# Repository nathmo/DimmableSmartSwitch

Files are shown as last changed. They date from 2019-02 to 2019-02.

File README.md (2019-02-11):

DimmableSmartSwitch

This repo contains the schematic and the layout for an ESP32 based
dual channel smart dimmer.
The ESP32 is intended to run under ESP-easy (a firmware that with native support of MQTT and wifi).
This smart dimmer work for Inductive and Capacitive load both in AC or DC.
The circuit is triggered on crossing zero (if the Load power supply is AC)
The circuit contains a current sensing circuitery on both channel, 2 capacitive touch input and
a microphone to stream audio for voice recognition (on another device (like a raspberry pi)) and obviously the circuitery to dim the load
A PLC transcienver may be added in futur revision
(PLC transcienver : A chip that allow to transmit data over power line)

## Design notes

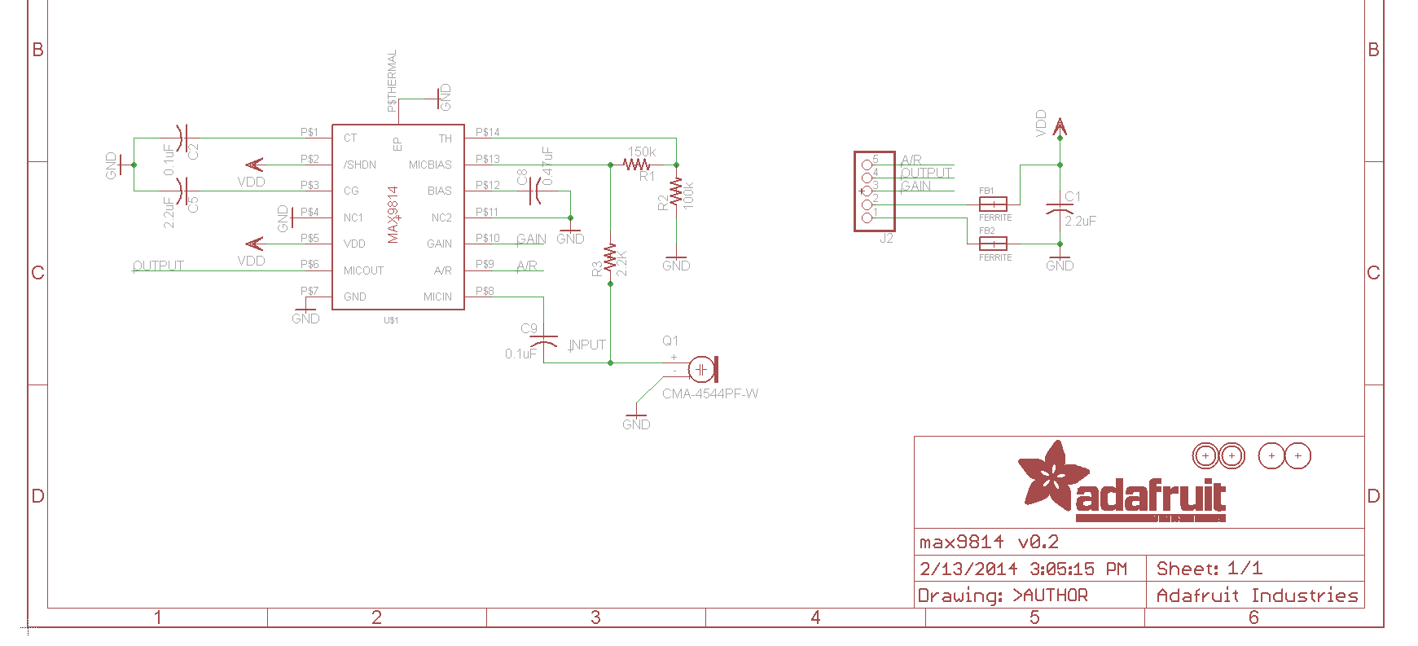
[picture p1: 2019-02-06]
adafruit_products_max9814sch.gif

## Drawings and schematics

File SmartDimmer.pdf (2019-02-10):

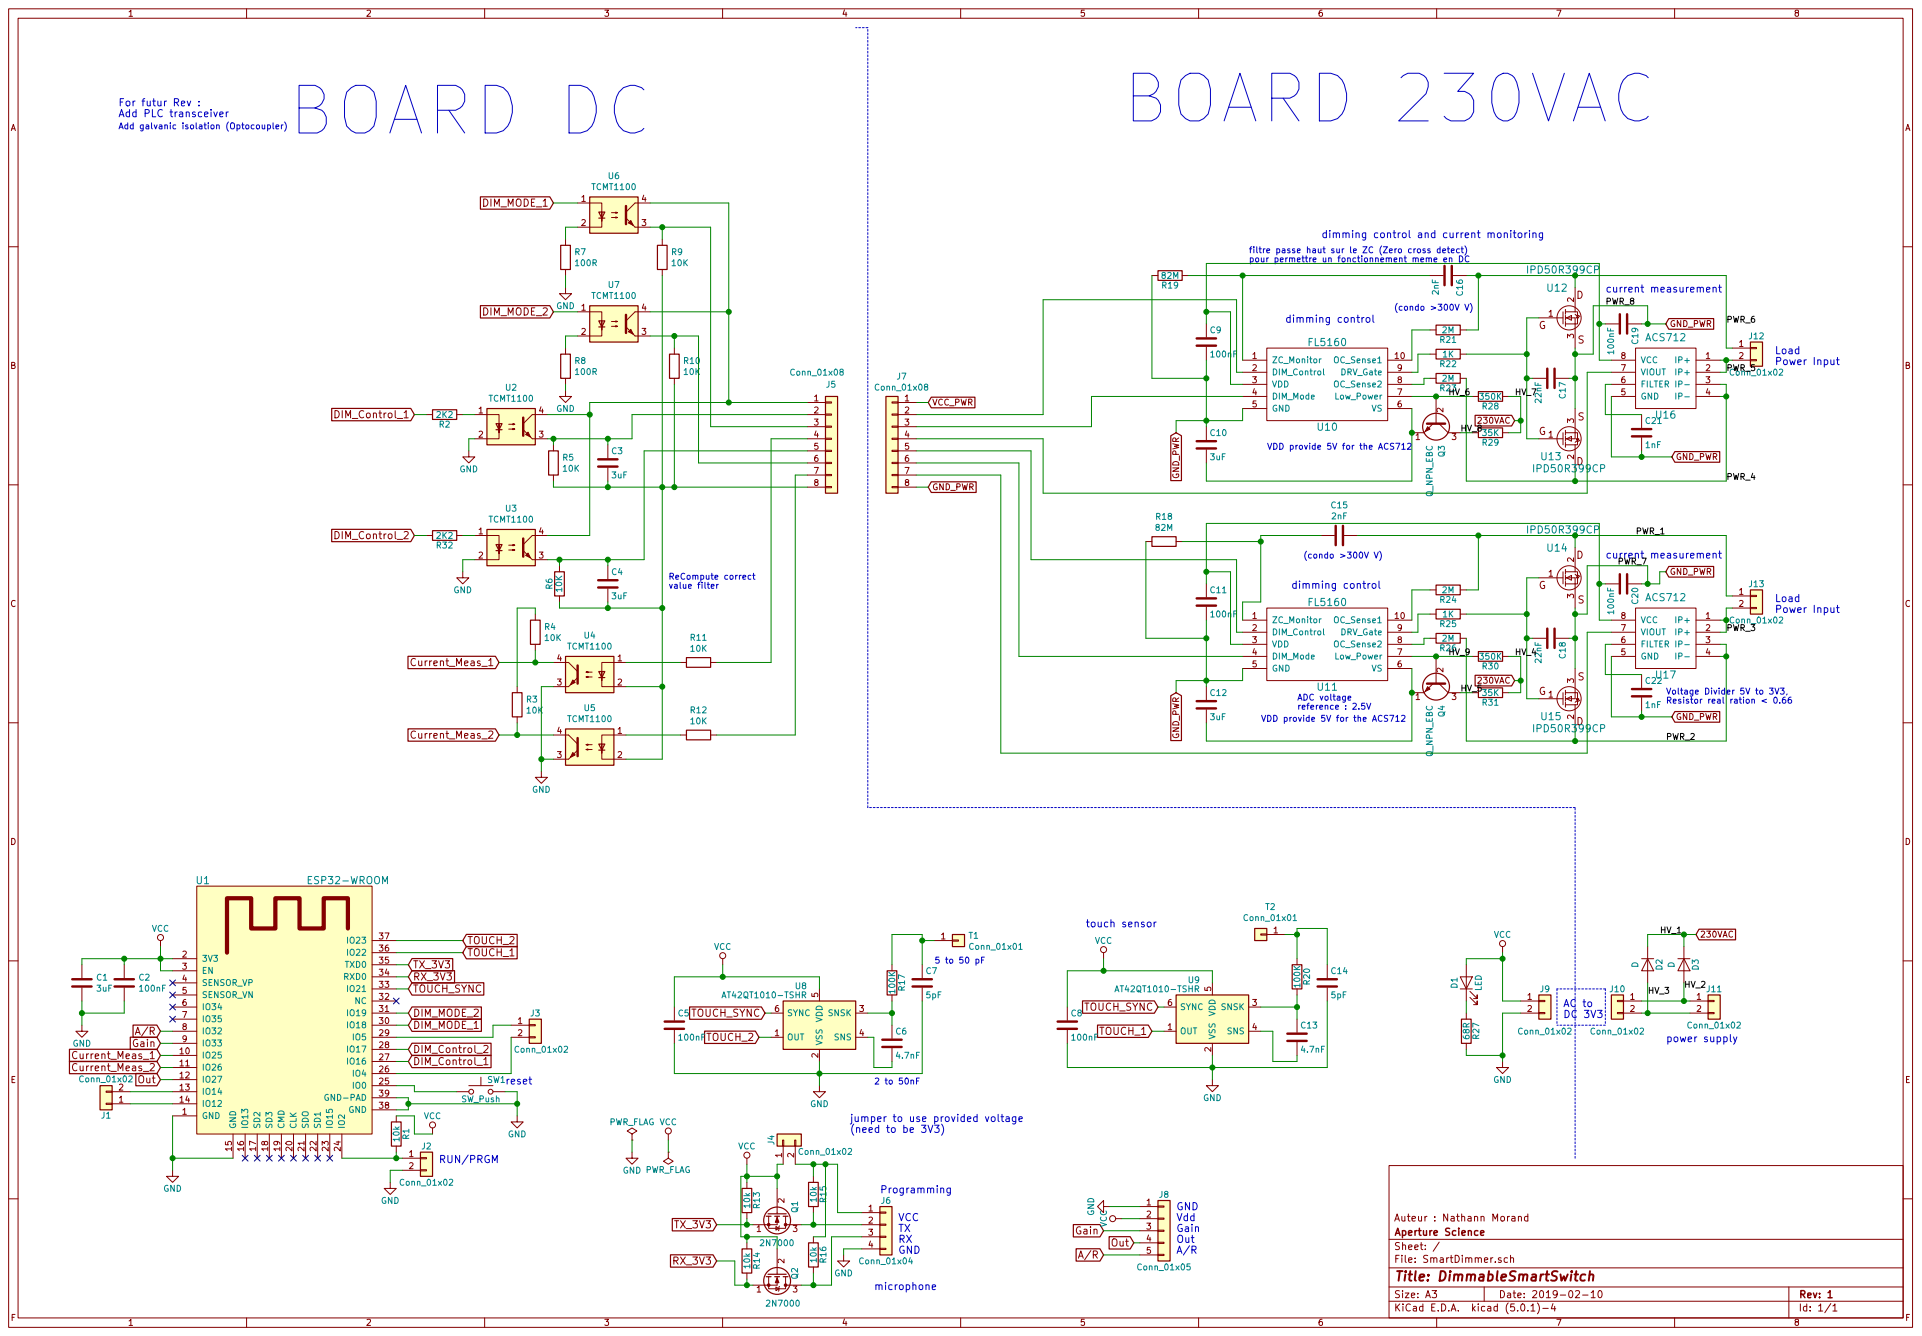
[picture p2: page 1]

For futur Rev : Add PLC transceiver

dimming control and current monitoring

filtre passe haut sur le ZC (Zero cross detect)

pour permettre un fonctionnement meme en DC R18

Load Power Input current measurement current measurement dimming control

VDD provide 5V for the ACS712

Voltage Divider 5V to 3V3, Resistor real ration < 0.66 ADC voltage

3V3 2 EN 3 SENSOR_VP 4 SENSOR_VN 5

5 SYNC 6 U8 AT42QT1010-TSHR OUT 1 VSS

File: SmartDimmer.sch Sheet: / Aperture Science Auteur : Nathann Morand GND 1

jumper to use provided voltage
(need to be 3V3)

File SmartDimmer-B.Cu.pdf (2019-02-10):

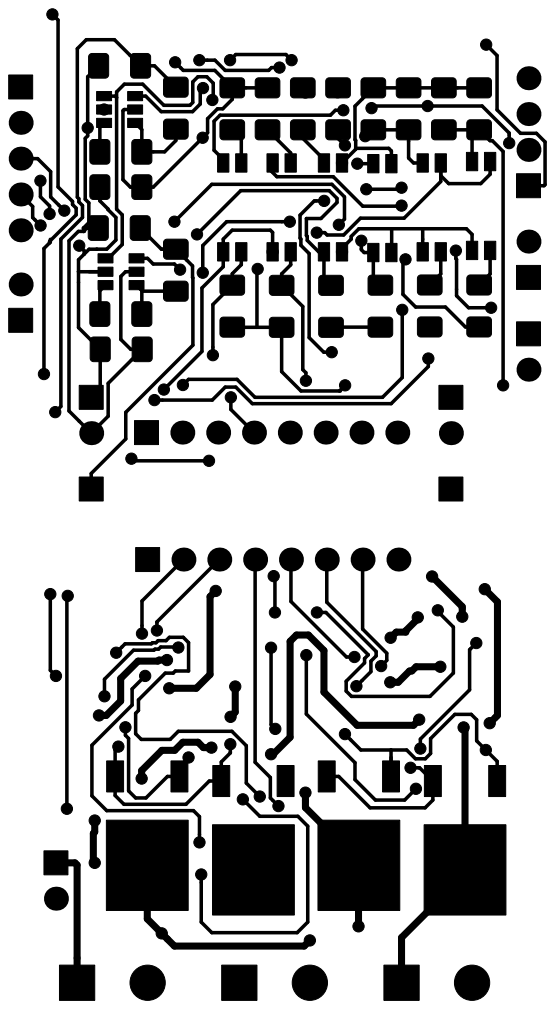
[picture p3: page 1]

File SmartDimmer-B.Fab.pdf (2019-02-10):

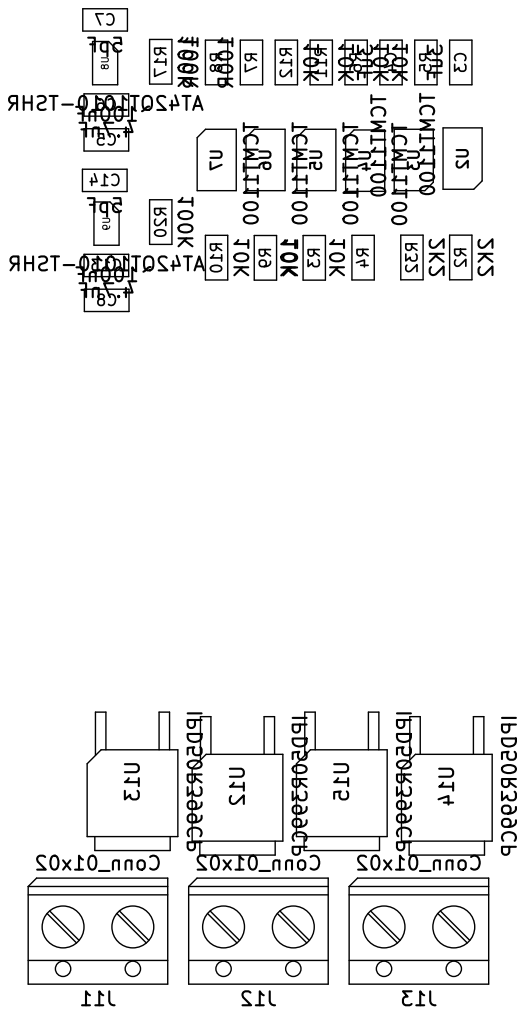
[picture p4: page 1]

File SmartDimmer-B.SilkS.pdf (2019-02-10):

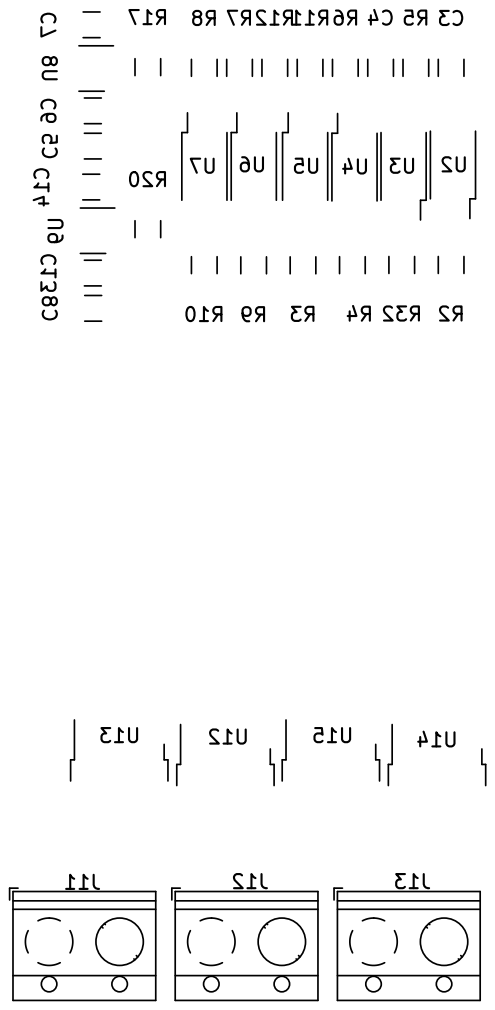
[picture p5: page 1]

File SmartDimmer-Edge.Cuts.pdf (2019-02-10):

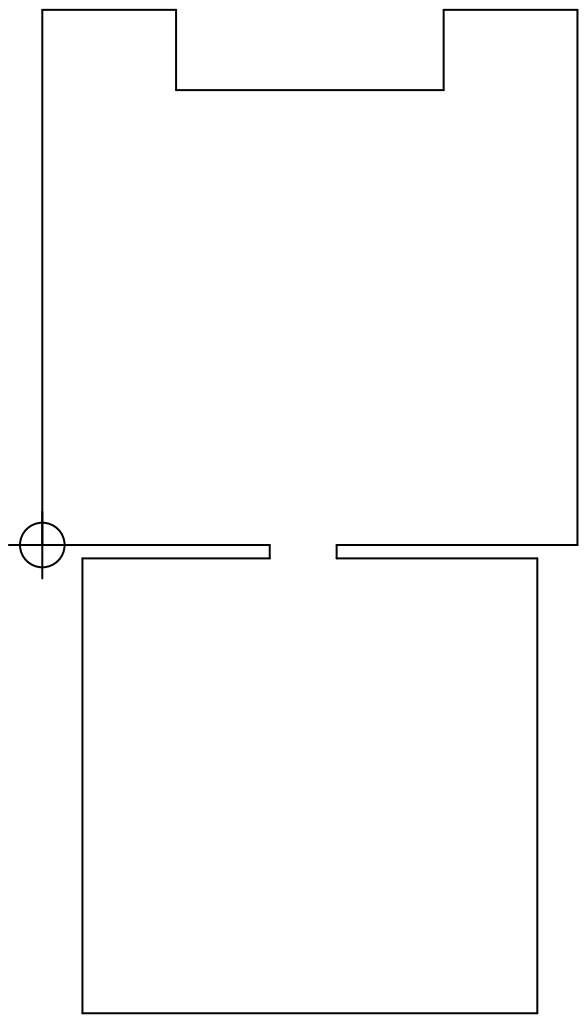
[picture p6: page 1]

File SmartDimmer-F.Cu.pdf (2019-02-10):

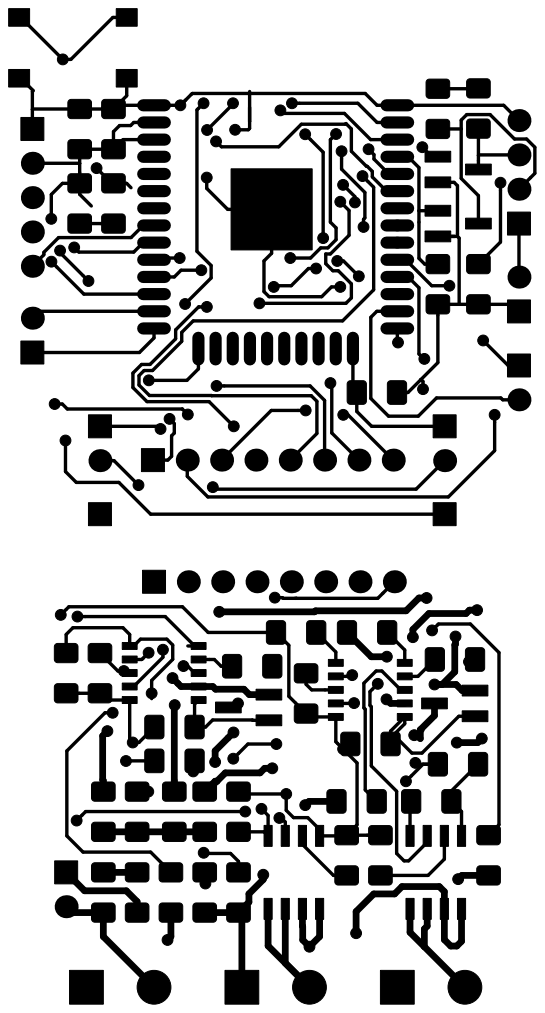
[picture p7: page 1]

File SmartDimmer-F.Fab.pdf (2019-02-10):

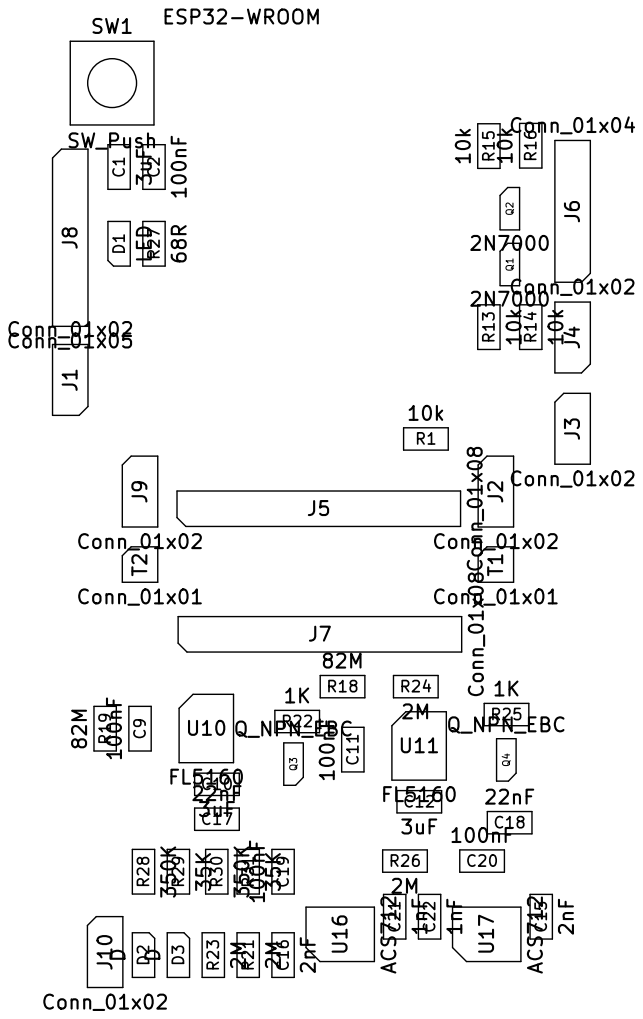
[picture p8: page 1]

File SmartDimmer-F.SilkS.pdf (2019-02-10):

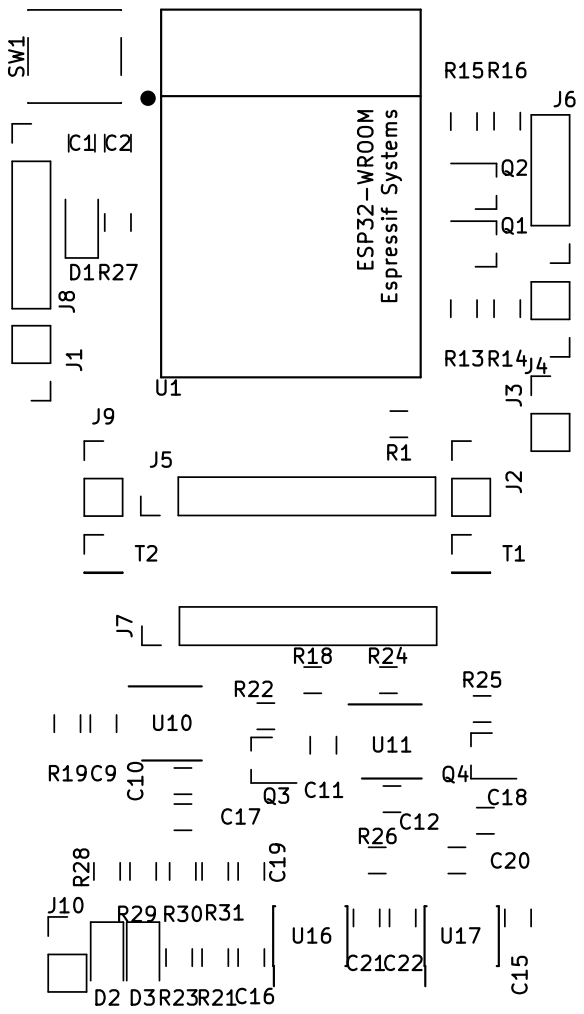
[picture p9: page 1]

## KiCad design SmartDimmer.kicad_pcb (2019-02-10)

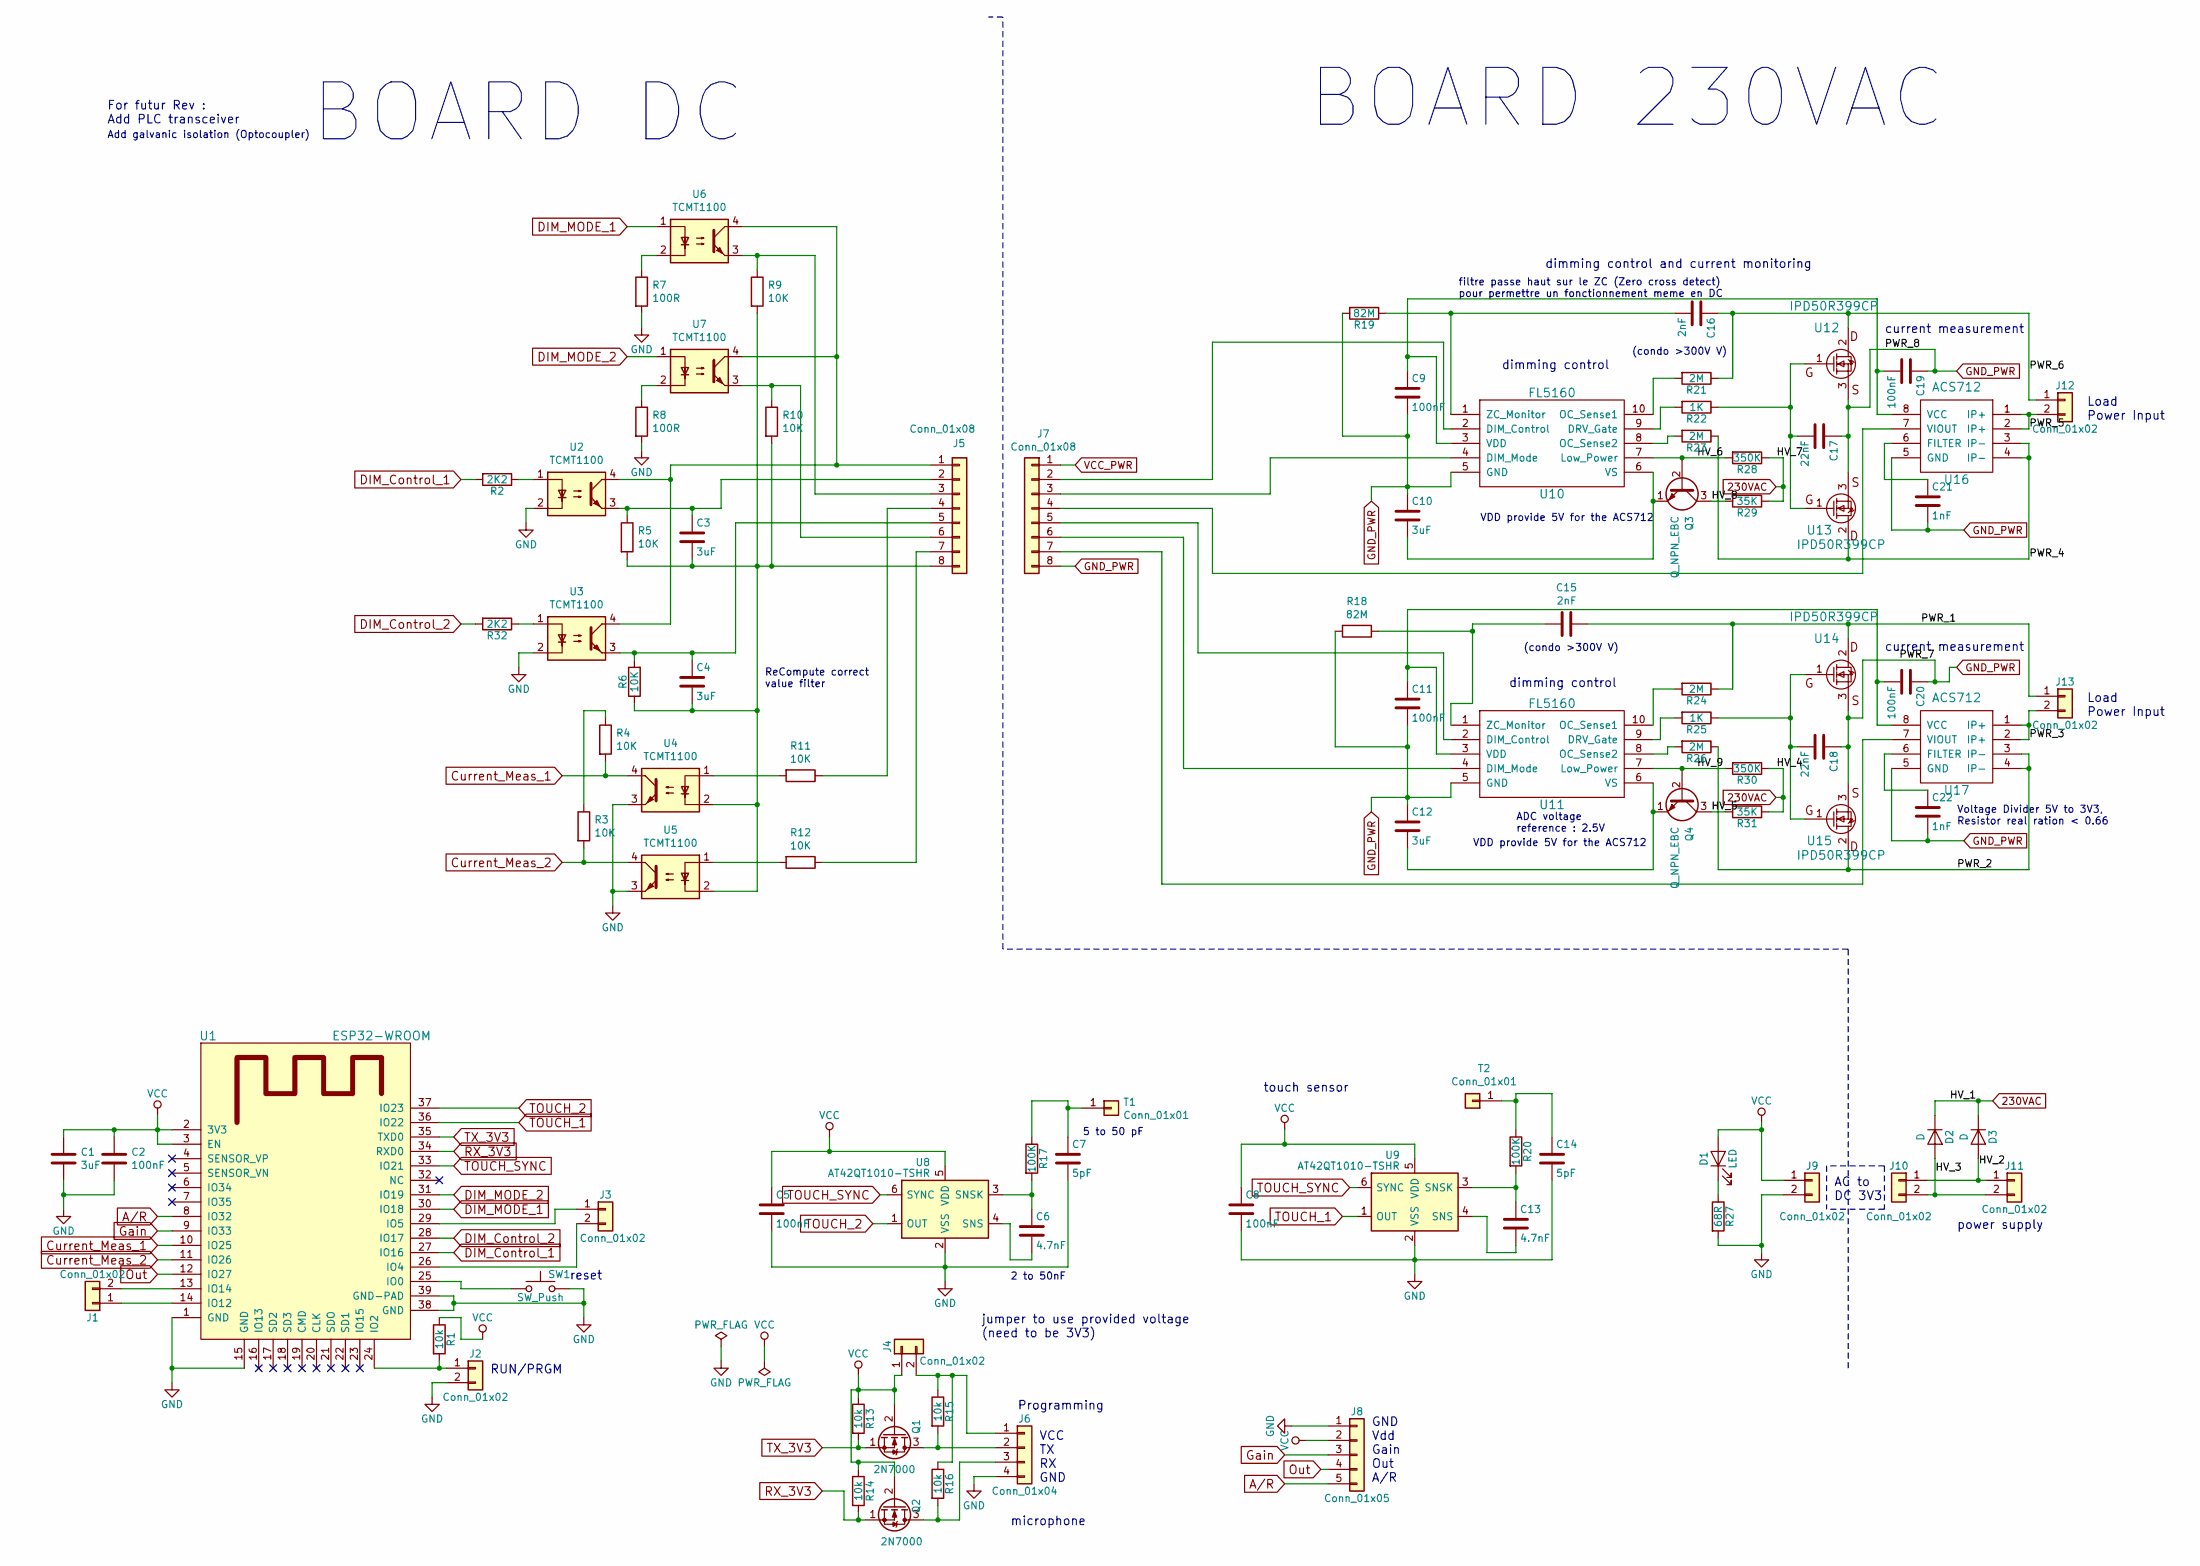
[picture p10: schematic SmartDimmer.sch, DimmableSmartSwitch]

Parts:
C1, C3, C4, C10, C12: 3uF; C_1206_3216Metric_Pad1.42x1.75mm_HandSolder
C2, C5, C8, C9, C11, C19, C20: 100nF; C_1206_3216Metric_Pad1.42x1.75mm_HandSolder
C6, C13: 4.7nF; C_1206_3216Metric_Pad1.42x1.75mm_HandSolder
C7, C14: 5pF; C_1206_3216Metric_Pad1.42x1.75mm_HandSolder
C15, C16: 2nF; C_1206_3216Metric_Pad1.42x1.75mm_HandSolder
C17, C18: 22nF; C_1206_3216Metric_Pad1.42x1.75mm_HandSolder
C21, C22: 1nF; C_1206_3216Metric_Pad1.42x1.75mm_HandSolder
D1: LED; LED_1206_3216Metric_Pad1.42x1.75mm_HandSolder
D2, D3: D; D_1206_3216Metric_Pad1.42x1.75mm_HandSolder
J1, J2, J3, J4, J9, J10: Conn_01x02; PinHeader_1x02_P2.54mm_Vertical
J5, J7: Conn_01x08; PinHeader_1x08_P2.54mm_Vertical
J6: Conn_01x04; PinHeader_1x04_P2.54mm_Vertical
J8: Conn_01x05; PinHeader_1x05_P2.54mm_Vertical
J11, J12, J13: Conn_01x02; TerminalBlock_RND_205-00012_1x02_P5.00mm_Horizontal
Q1, Q2: 2N7000; SOT-23_Handsoldering
Q3, Q4: Q_NPN_EBC; SOT-23_Handsoldering
R1, R13, R14, R15, R16: 10k; R_1206_3216Metric_Pad1.42x1.75mm_HandSolder
R2, R32: 2K2; R_1206_3216Metric_Pad1.42x1.75mm_HandSolder
R3, R4, R5, R6, R9, R10, R11, R12: 10K; R_1206_3216Metric_Pad1.42x1.75mm_HandSolder
R7, R8: 100R; R_1206_3216Metric_Pad1.42x1.75mm_HandSolder
R17, R20: 100K; R_1206_3216Metric_Pad1.42x1.75mm_HandSolder
R18, R19: 82M; R_1206_3216Metric_Pad1.42x1.75mm_HandSolder
R21, R23, R24, R26: 2M; R_1206_3216Metric_Pad1.42x1.75mm_HandSolder
R22, R25: 1K; R_1206_3216Metric_Pad1.42x1.75mm_HandSolder
R27: 68R; R_1206_3216Metric_Pad1.42x1.75mm_HandSolder
R28, R30: 350K; R_1206_3216Metric_Pad1.42x1.75mm_HandSolder
R29, R31: 35K; R_1206_3216Metric_Pad1.42x1.75mm_HandSolder
SW1: SW_Push; SW_SPST_PTS645
T1, T2: Conn_01x01; PinHeader_1x01_P2.54mm_Vertical
U1: ESP32-WROOM
U2, U3, U4, U5, U6, U7: TCMT1100; SOP-4_4.4x2.8mm_P1.27mm
U8, U9: AT42QT1010-TSHR; SOT-23-6
U10, U11: FL5160; SSOP-10_3.9x4.9mm_P1.00mm
U12, U13, U14, U15: IPD50R399CP; TO-252-2
U16, U17: ACS712; SOIC-8_3.9x4.9mm_P1.27mm

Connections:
230VAC: D2.1 (K), D3.1 (K), R28.1, R29.1, R30.1, R31.1
/HV_2: D3.2 (A), J10.1, J11.1
/HV_3: D2.2 (A), J10.2, J11.2
/HV_5: Q4.3 (C), R31.2
/HV_6: Q3.2 (B), R28.2, U10.7 (Low_Power)
/HV_8: Q3.3 (C), R29.2
/HV_9: Q4.2 (B), R30.2, U11.7 (Low_Power)
/PWR_1: C15.1, J13.1, R24.1, U14.2
/PWR_2: R26.1, U15.2, U17.3 (IP-), U17.4 (IP-)
/PWR_3: J13.2, U17.1 (IP+), U17.2 (IP+)
/PWR_4: R23.1, U13.2, U16.3 (IP-), U16.4 (IP-)
/PWR_5: J12.2, U16.1 (IP+), U16.2 (IP+)
/PWR_6: C16.1, J12.1, R21.1, U12.2
A/R: J8.5, U1.8 (IO32)
Current_Meas_1: R4.2, U1.10 (IO25), U4.4
Current_Meas_2: R3.2, U1.11 (IO26), U5.4
DIM_Control_1: R2.2, U1.27 (IO16)
DIM_Control_2: R32.2, U1.28 (IO17)
DIM_MODE_1: U1.30 (IO18), U6.1
DIM_MODE_2: U1.31 (IO19), U7.1
GND: C1.2, C2.2, C5.2, C7.2, C8.2, C14.2, J2.2, J6.4, J8.1, J9.2, R7.2, R8.2, R27.2, SW1.2, U1.1 (GND), U1.15 (GND), U1.38 (GND), U1.39 (GND-PAD), U2.2, U3.2, U4.3, U5.3, U8.2 (VSS), U9.2 (VSS)
GND_PWR: C9.2, C10.1, C11.2, C12.1, C17.1, C18.1, C19.1, C20.1, C21.2, C22.2, J7.8, R18.2, R19.2, U10.5 (GND), U11.5 (GND), U12.3, U13.3, U14.3, U15.3, U16.5 (GND), U17.5 (GND)
Gain: J8.3, U1.9 (IO33)
unnamed: C3.1, J5.2, R5.1, U2.3
unnamed: C3.2, C4.2, J5.8, R5.2, R6.1, R9.2, R10.2, U4.2, U5.2
unnamed: C4.1, J5.5, R6.2, U3.3
unnamed: C6.1, R17.2, U8.3 (SNSK)
unnamed: C6.2, U8.4 (SNS)
unnamed: C7.1, R17.1, T1.1
unnamed: C10.2, Q3.1 (E), U10.6 (VS)
unnamed: C11.1, C20.2, U11.3 (VDD), U17.8 (VCC)
unnamed: C12.2, Q4.1 (E), U11.6 (VS)
unnamed: C13.1, R20.2, U9.3 (SNSK)
unnamed: C13.2, U9.4 (SNS)
unnamed: C14.1, R20.1, T2.1
unnamed: C15.2, R18.1, U11.1 (ZC_Monitor)
unnamed: C16.2, R19.1, U10.1 (ZC_Monitor)
unnamed: C17.2, R22.1, U12.1, U13.1
unnamed: C18.2, R25.1, U14.1, U15.1
unnamed: C9.1, C19.2, U10.3 (VDD), U16.8 (VCC)
unnamed: C21.1, U16.6 (FILTER)
unnamed: C22.1, U17.6 (FILTER)
unnamed: D1.1 (K), R27.1
unnamed: J1.1, U1.14 (IO12)
unnamed: J1.2, U1.13 (IO14)
unnamed: J2.1, R1.2, U1.24 (IO2)
unnamed: J3.1, U1.29 (IO5)
unnamed: J3.2, U1.26 (IO4)
unnamed: J4.2, J6.1, R15.1, R16.1
unnamed: J5.1, U2.4, U3.4, U6.4, U7.4
unnamed: J5.3, R9.1, U6.3
unnamed: J5.4, R11.1
unnamed: J5.6, R10.1, U7.3
unnamed: J5.7, R12.1
unnamed: J6.2, Q1.3 (D), R15.2
unnamed: J6.3, Q2.3 (D), R16.2
unnamed: J7.2, U10.2 (DIM_Control)
unnamed: J7.3, U10.4 (DIM_Mode)
unnamed: J7.4, U16.7 (VIOUT)
unnamed: J7.5, U11.2 (DIM_Control)
unnamed: J7.6, U11.4 (DIM_Mode)
unnamed: J7.7, U17.7 (VIOUT)
unnamed: R2.1, U2.1
unnamed: R3.1, R4.1
unnamed: R7.1, U6.2
unnamed: R8.1, U7.2
unnamed: R11.2, U4.1
unnamed: R12.2, U5.1
unnamed: R21.2, U10.10 (OC_Sense1)
unnamed: R22.2, U10.9 (DRV_Gate)
unnamed: R23.2, U10.8 (OC_Sense2)
unnamed: R24.2, U11.10 (OC_Sense1)
unnamed: R25.2, U11.9 (DRV_Gate)
unnamed: R26.2, U11.8 (OC_Sense2)
unnamed: R32.1, U3.1
unnamed: SW1.1, U1.25 (IO0)
Out: J8.4, U1.12 (IO27)
RX_3V3: Q2.1 (S), R14.2, U1.34 (RXD0)
TOUCH_1: U1.36 (IO22), U9.1 (OUT)
TOUCH_2: U1.37 (IO23), U8.1 (OUT)
TOUCH_SYNC: U1.33 (IO21), U8.6 (SYNC), U9.6 (SYNC)
TX_3V3: Q1.1 (S), R13.2, U1.35 (TXD0)
VCC: C1.1, C2.1, C5.1, C8.1, D1.2 (A), J4.1, J8.2, J9.1, Q1.2 (G), Q2.2 (G), R1.1, R13.1, R14.1, U1.2 (3V3), U1.3 (EN), U8.5 (VDD), U9.5 (VDD)

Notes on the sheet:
power supply
touch sensor
Load Power Input
dimming control and current monitoring
Programming
microphone
For futur Rev : Add PLC transceiver
AC to DC 3V3
jumper to use provided voltage (need to be 3V3)
VCC TX RX GND
reset
RUN/PRGM
current measurement
dimming control
GND Vdd Gain Out A/R
filtre passe haut sur le ZC (Zero cross detect) pour permettre un fonctionnement meme en DC
(condo >300V V)
2 to 50nF
5 to 50 pF
Voltage Divider 5V to 3V3, Resistor real ration < 0.66
ADC voltage reference : 2.5V
BOARD 230VAC
BOARD DC
VDD provide 5V for the ACS712
Add galvanic isolation (Optocoupler)
ReCompute correct value filter

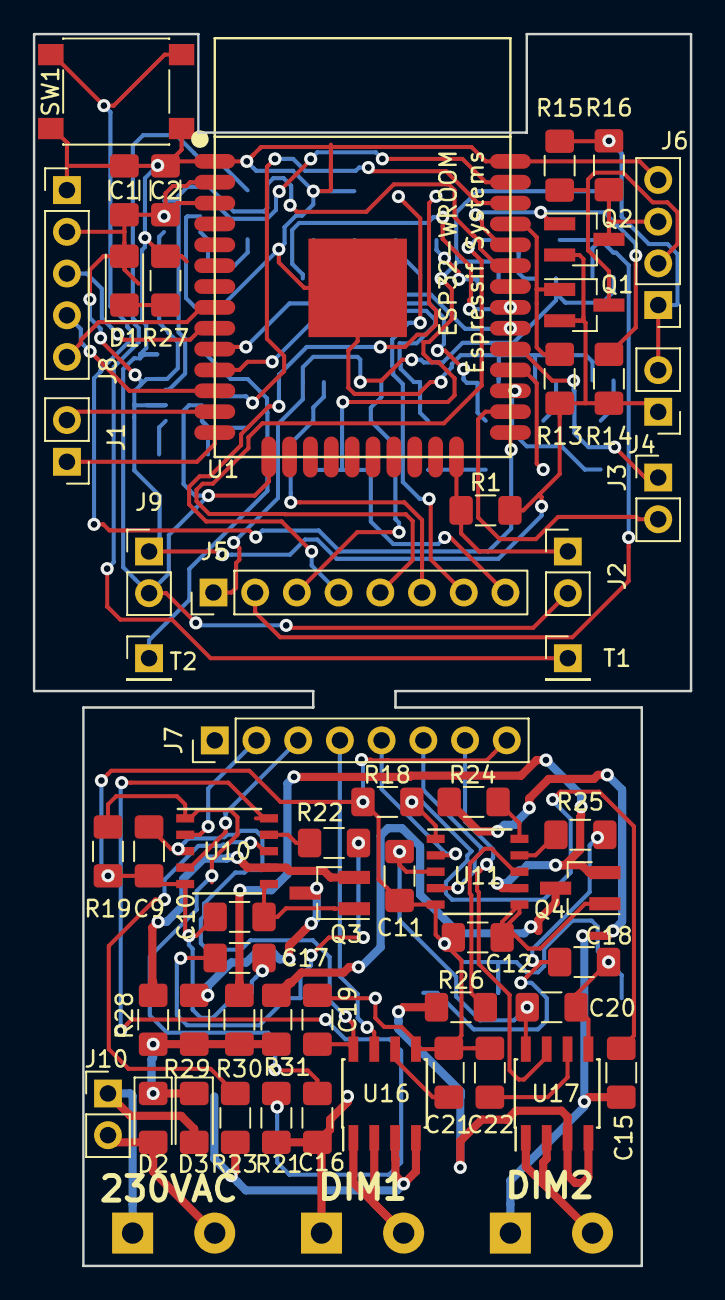
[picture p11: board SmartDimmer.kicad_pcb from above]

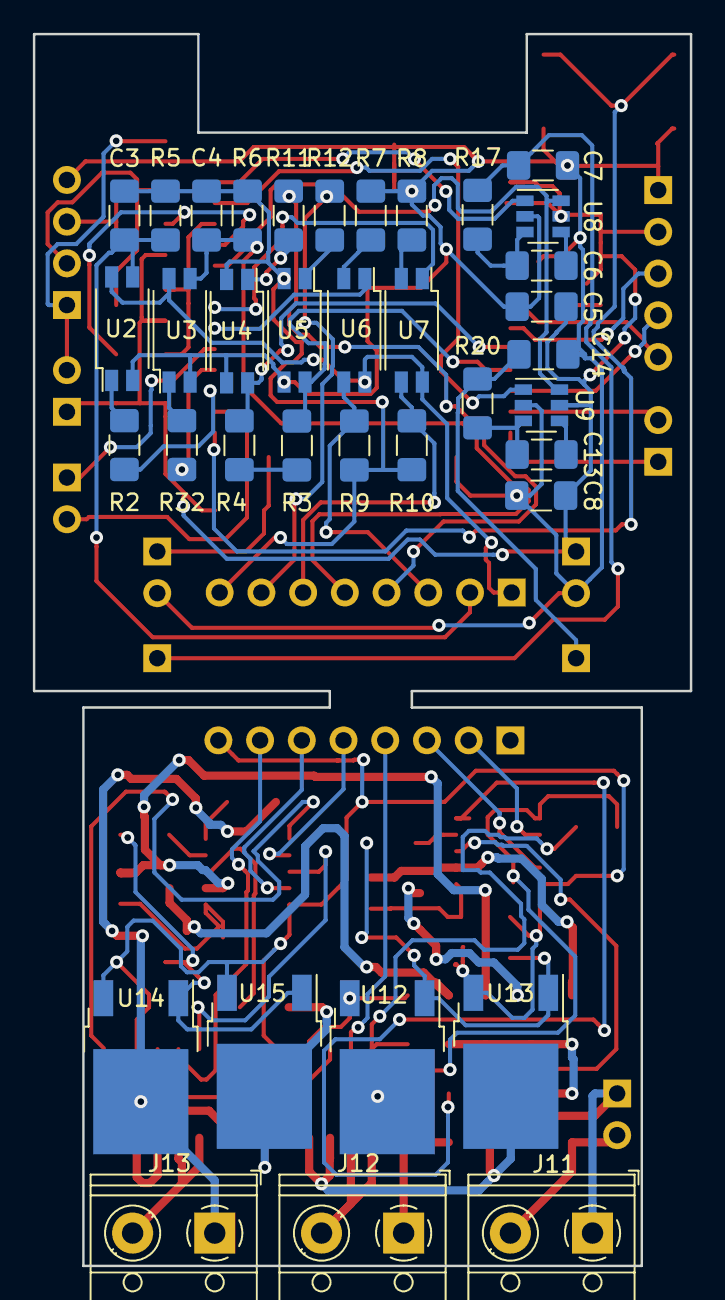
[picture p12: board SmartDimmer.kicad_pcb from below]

Board: 2 copper layers, 40.0 x 75.0 mm, 94 parts (37 on the bottom side), 83 nets.

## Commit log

2019-01-27 First commit, most of the component have been selected
    [SmartDimmer.kicad_pcb, SmartDimmer.sch]
2019-01-27 finished the shematic, the value of the component need to be calculated
    [SmartDimmer.sch]
2019-02-06 Schematic update
    [SmartDimmer-2019-02-06-13-15-49.sch, SmartDimmer.sch]
2019-02-06 added datasheet
    [SmartDimmer.sch]
2019-02-10 Rework of the schematic and started the layout
    [SmartDimmer.dsn, SmartDimmer.sch]
2019-02-10 added PDF
    [SmartDimmer.kicad_pcb, SmartDimmer.sch]
2019-02-10 aestetic change
    [SmartDimmer.kicad_pcb]
